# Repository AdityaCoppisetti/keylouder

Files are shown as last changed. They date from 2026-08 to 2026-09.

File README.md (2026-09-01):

hey im dhruv coppisetti and i love mechanical keyboards!
mainly 60 percents to be honest. 

with hackclub's macondo program where they fund you for the project that you make,
i decided that i should give this project a try and for the longest time i left it
abandoned because i couldn't figure out the keyboard layout, but then i watched a ton of
youtube tutorials and i got the hang of it. 

how is my keyboard different than other 60 percent keyboards?

well for starters its made completely by me including the pcb and the case and everything down to the tiniest bit

and then i did this really unique thing all because i had a tiny bit of space beneath the main controller of the keyboard (raspberry pi pico)
so i thought i should add a led matrix.

i was loooking at a tutorial where they had made their own led matrix module and it got me thinking what if i made my own
hotswappable modules

and so i did just that 

i made the keyboards pcb firstly and here is how that looks like 



but the wiring and the annotation was all wrong so i made it again plus i had totally forgotton to add stabilizers

so i made the schematic again and made a new pcb 



i landed with this pcb 



and the extra space beneath the pi pico gave me the idea and the space to add swappable modules 



and so i made a led matrix pcb and here is how that looks like 



the routing for this pcb took me A WHILLLEEE but i had  tons of fun doing it 
its really fun to take such tasks 

and the led matrix went onto the board so perfectly 

https://github.com/user-attachments/assets/e525fbdb-a991-4f65-9065-cdec64515798

and then i made 2 more modules 

the rotary encoder pcb which just changes the wiring 





i will be using that to adjust volume

and the most exciting part of the project is that i made a virtual pet inside the keyboard!

i made a tamagotchi module.

what a tamgotchi?

Tamagotchi is a brand of handheld digital pets created by Japanese toymaker Bandai, originally released in 1996.  The name is a portmanteau of the Japanese word tamago (egg) and watch, reflecting the device's egg-shaped design.

its a tiny digital pet 

i didnt have enough remaining pins on the pi pico so i made a esp32 devboard and then made it into a tiny module 





and then i wanted a skeleton case for the keyboard so i made this case on onshape 







although i might redesign the led matrix pcb again


im super duper excited to build this project when i get the funding for it. you can find all the resources i used in the journal.md in this repo

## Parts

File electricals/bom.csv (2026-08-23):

Module | Component | Quantity | Price (INR) | Link | Price (USD)
Keyboard | Raspberry Pi Pico | 1 | 1060 | https://amzn.in/d/02R50tLO | $11.08
Keyboard | 1N4148 DO-35 switching diode | 61 | 294 | https://robu.in/product/1n4148-onsemi-100v-1v10ma-4ns-200ma-do-35-switching-diodes-rohs/ | $3.07
Keyboard | Womier Retro Ruby Pink Cherry Doubleshot PBT Keycaps | 1 | 1899 | https://curiositycaps.in/products/womier-retro-ruby-pink-cherry-doubleshot-pbt-keycaps | $19.84
Keyboard | Blue mechanical switches | 90 | 2187 | https://amzn.in/d/03xjlYV7 | $22.85
Keyboard | Keyboard stabilizers | 1 | 1716 | https://amzn.in/d/0fbE7VLn | $17.93
Keyboard | 2.00mm pitch female Berg strip | 1 | 25 | https://robu.in/product/2mm-pitch-female-berg-strip-40x1-2pcs/ | $0.26
Keyboard | Keyboard PCB | 1 | 900 | robu.in | $9.40
Rotary Encoder | Rotary encoder module | 1 | 92 | https://robu.in/product/m274-360-degree-rotary-encoder-module-brick-sensor/ | $0.96
Rotary Encoder | Perfboard | 1 | 75 | https://amzn.in/d/09jRTxoF | $0.78
Rotary Encoder | 360-degree rotary encoder module | 1 | 92 | https://robu.in/product/m274-360-degree-rotary-encoder-module-brick-sensor/ | $0.96
LED Matrix | 100nF / 0.1uF 0603 SMD ceramic capacitor | 1 | 4.4 | https://robu.in/product/0603b104k101nt-fh-100v-100nf-x7r%c2%b110-0603-multilayer-ceramic-capacitors-mlcc-smd-smt-rohs/ | $0.05
LED Matrix | 10uF 0603 SMD ceramic capacitor | 1 | 39 | https://robu.in/product/zrb18ar61e106me01l-murata-smd-multilayer-ceramic-capacitor-10-%c2%b5f-25-v-0603-1608-metric-%c2%b1-20-x5r-zrb/ | $0.41
LED Matrix | 0603 SMD red LED | 64 | 133 | https://robu.in/product/19-217-r6c-al1m2vy-3t-everlight-red-528nm-led-indication-discrete-3-3v-0603-1608-metric/ | $1.39
LED Matrix | 10k 0603 SMD resistor | 1 | 4.8 | https://robu.in/product/yageo-10k-ohm-1-4w-0603-surface-mount-chip-resistor-pack-of-50/ | $0.05
LED Matrix | MAX7219 SMD IC | 1 | 128 | https://robu.in/product/max7219-ic-smd-package-8-digit-led-display-driver-ic/ | $1.34
LED Matrix | PCB | 1 | 900 | https://robu.in/ | $9.40
Tamagotchi | GC9A01 1.28-inch 240x240 round display | 1 | 519 | https://robu.in/product/goldenmorning-gc9a01-7p-240x240-spi-1-28-inch-round-display-module/ | $5.42
Tamagotchi | 6x6mm through-hole tactile switch | 1 | 7 | https://robu.in/product/tsd001a06026a-bzcn-6mm-6mm-50ma-round-button-direct-insert-6mm-12v-plugin-tactile-switches-rohs/ | $0.07
Tamagotchi | PCB | 1 | 900 | https://robu.in/ | $9.40
 |  |  |  | total amount is 115 dollars

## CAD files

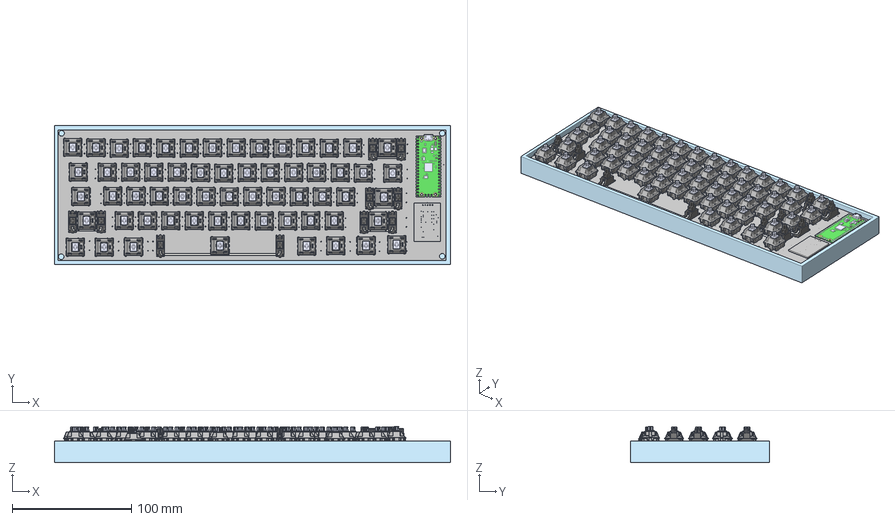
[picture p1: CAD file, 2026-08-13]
CAD/keyboard assembly.step
331.6 x 116.6 x 30.5 mm
Stabilizer_Cherry_MX_2.00u x 5
???___???__??___���___Ĭ��_ _��_ x 122
MX ?? ??????_????____MX �� ���娢��_ ���顧__ x 61
MX ?? ??????_??___??1__MX �� ������_ ��___��1 x 61
Stabilizer_Cherry_MX_2.00u_1 x 5
MX?? ???? ??? ???2__???_??2____??___MX�� ���� �ײ� �̡�2__Ĭ��_��2 ____��_ x 61
Stabilizer_Cherry_MX_2.00u_3 x 5
Stabilizer_Cherry_MX_2.00u_2 x 5
Stabilizer_Cherry_MX_6.25u x 5
led matrix_PCB
keeb_PCB
PICO

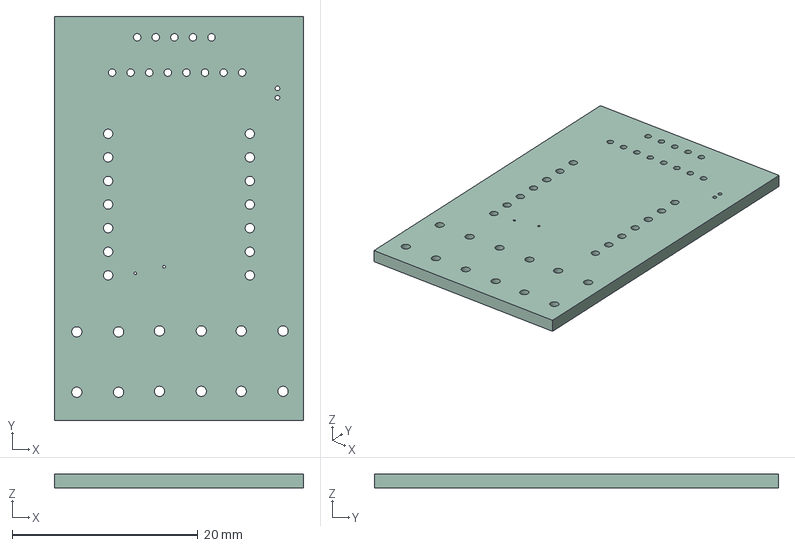
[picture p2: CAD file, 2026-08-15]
CAD/better tamagotchi module.step
26.8 x 43.5 x 1.51 mm

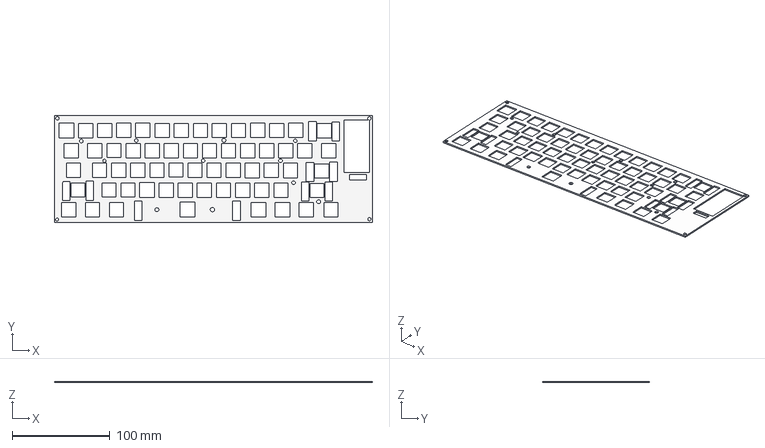
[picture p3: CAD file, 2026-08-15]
CAD/top plate.step
324.9 x 109.2 x 1.50 mm

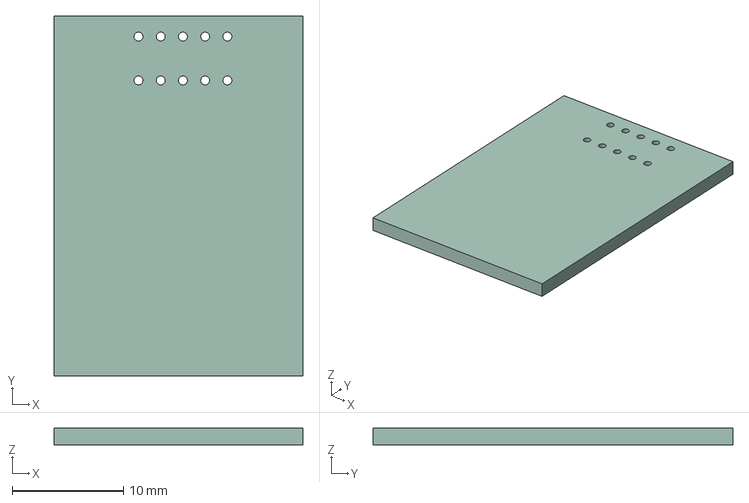
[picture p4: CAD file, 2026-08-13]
CAD/rotary encoder module.step
22.4 x 32.4 x 1.51 mm

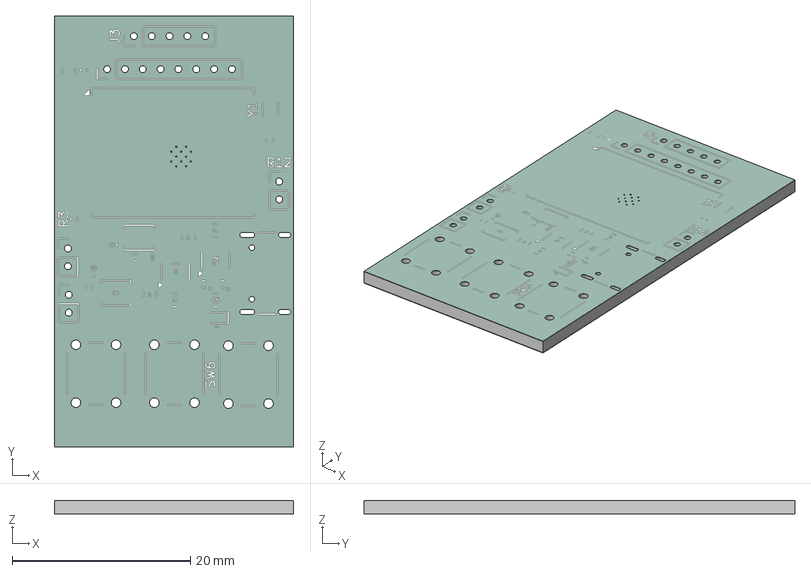
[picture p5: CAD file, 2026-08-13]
CAD/tamagotchi module.step
26.8 x 48.3 x 1.64 mm
tamagotchi module_silkscreen
tamagotchi module_soldermask x 2
tamagotchi module_PCB

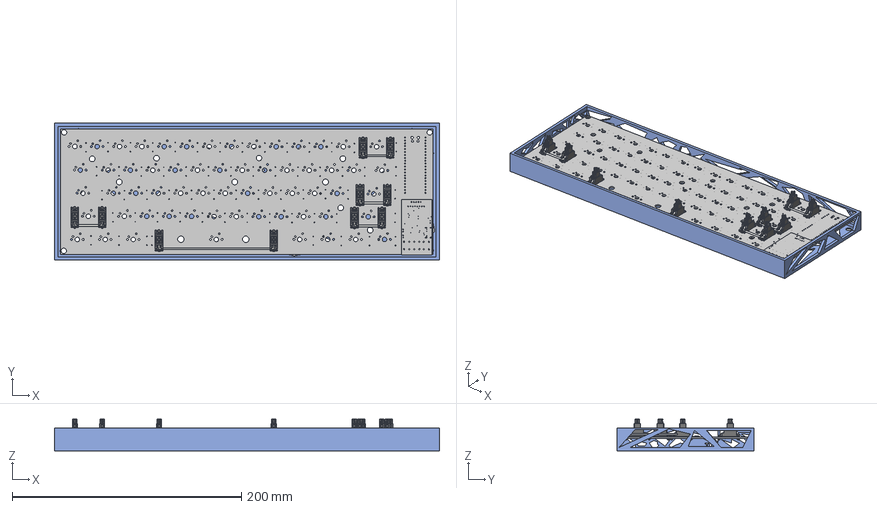
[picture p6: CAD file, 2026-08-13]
CAD/keylouder skeleton case version 1.step
335.8 x 119.3 x 27.8 mm
Stabilizer_Cherry_MX_2.00u_3 x 5
Stabilizer_Cherry_MX_2.00u x 5
Stabilizer_Cherry_MX_2.00u_1 x 5
tamagotchi module_PCB
Stabilizer_Cherry_MX_2.00u_2 x 5
Stabilizer_Cherry_MX_6.25u x 5
keeb_PCB

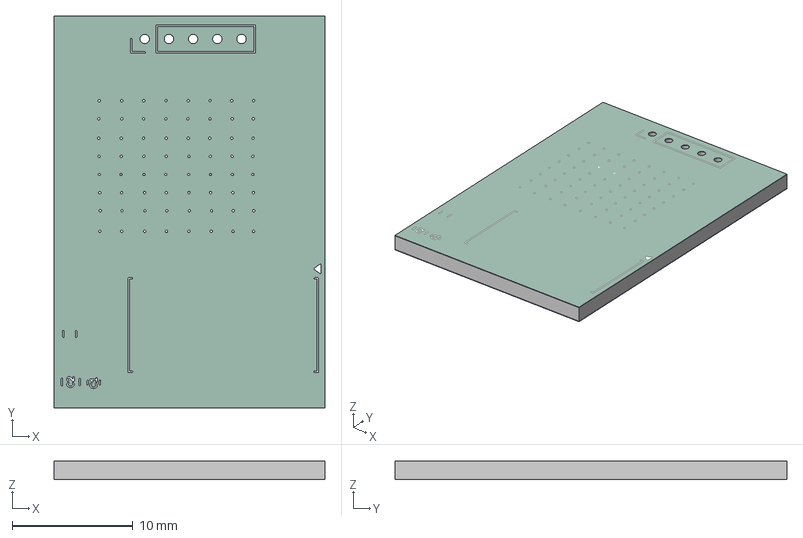
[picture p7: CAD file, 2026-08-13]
CAD/led matrix.step
22.4 x 32.4 x 1.64 mm
led matrix_silkscreen
led matrix_soldermask x 2
led matrix_PCB

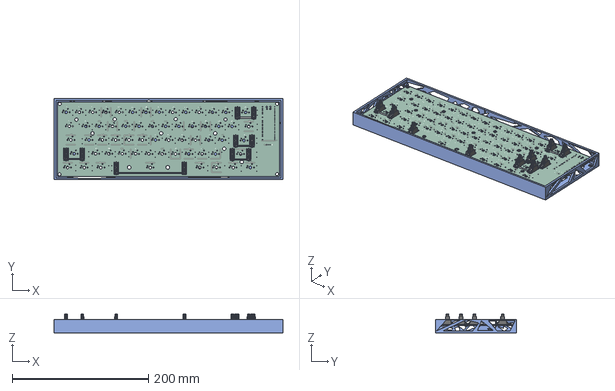
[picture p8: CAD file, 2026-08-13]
CAD/keylouder skeleton case final.step
335.8 x 119.3 x 27.8 mm

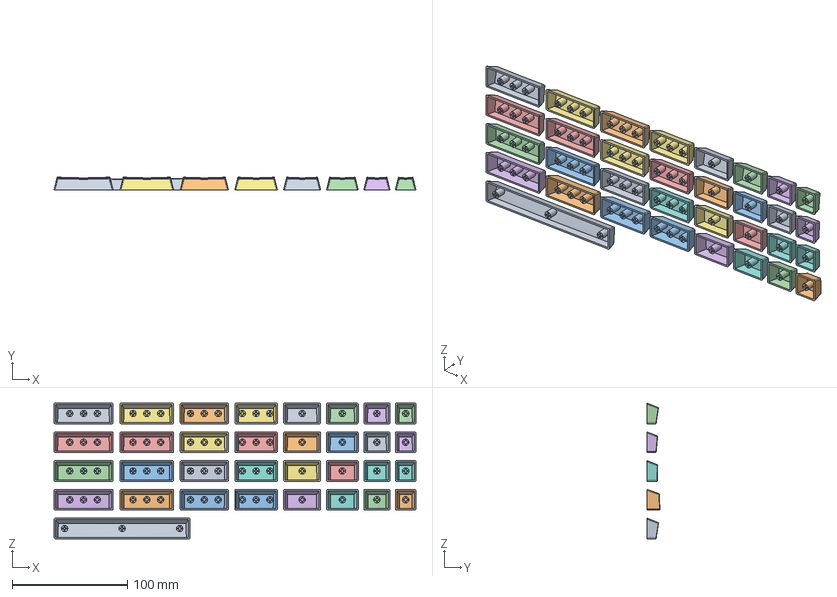
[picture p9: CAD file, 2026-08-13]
CAD/Cherry MX keycaps.step
314.7 x 11.2 x 118.0 mm

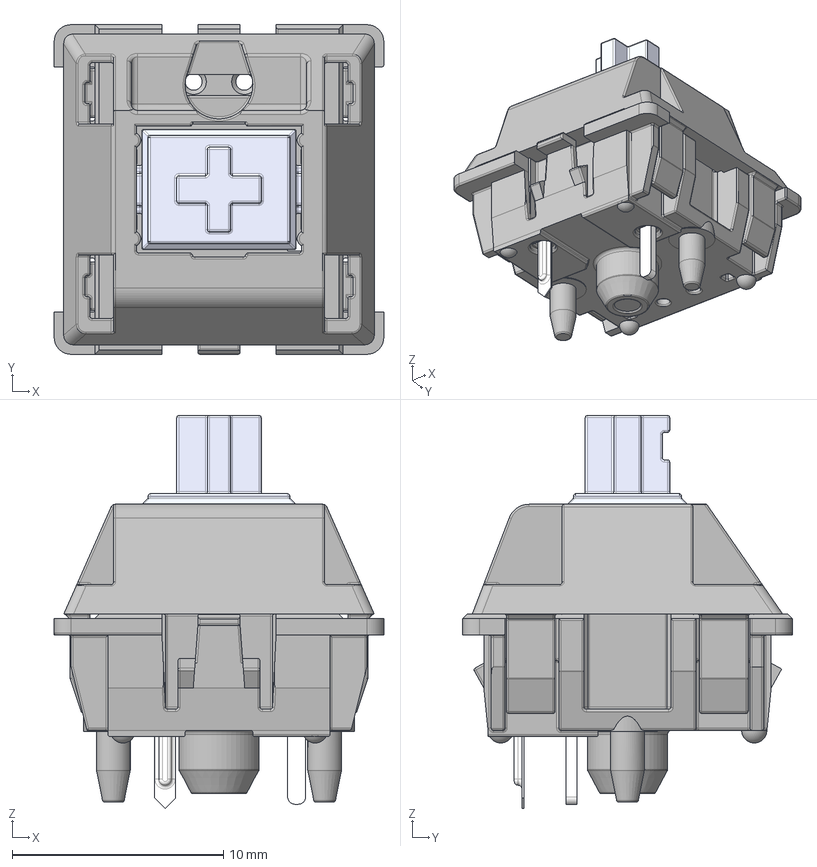
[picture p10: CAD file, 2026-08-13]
CAD/Cherry MX Keyswitch.step
15.6 x 15.6 x 18.6 mm

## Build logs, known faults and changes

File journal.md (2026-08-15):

i started this project back in june? 
i cant really rememeber but then i abandoned this project because i couldnt understand the keyboard layout and the pcb mapping. 
well some youtube tutorials later i figured how to make the layout. 

i went to this website to figure out the keyboard layout what is basically does is it shows you the keyboard layout and the size of the keys. 

https://editor.keyboard-tools.xyz/

you see something like this when you open the website , you can use whichever website you find comfortable, for me its this website. 



there are pre-existing presets , you can even build you custom presets,
then you can choose whichever keyboard layout you want.



i decided to make a 60% keyboard since i already have a 60% keyboard and i love its layout

it looks like this- 



and then you open kicad and then open schematic editor and take a switch and diode. 
why? 
because there are 61 switches and we are using the raspberry pico which clearly doesnt have the pins required to wire each switch seperately. 

# THE SCHEMATIC

so here is what we are going to do , we are going to make a matrix of switches in this manner- 



and then we will wire them up in rows and columns like this- 



3 rows and 3 columns, this is basic maths combination. 

okay ill quickly explain the wiring diagram. 

and the diodes are there so no swtiches falsly seem to be pressed , i.e ghost clicking

so basically each switch is now unique since it has a unique value . 
for example switch one is wired so that when pressed it'll be - row1 and column 1. and for switch 2 it'll be row2 and column1 

okay so using this idea we make the full schematic for the needed 61 keys ( because its 60%) 

okay so this schematic wiring is a bit wrong, i need to fix it but it explains the logic. 



see the rows and columns 

we will call this schematic version 1 



just for understanding the logic 

i even made the entire pcb but then i realised i wired everything wrong , here is that pcb i designed- 

Screenshot From 2026-08-11 15-16-31

okay i copied over the components and lets redesign the schematic . 



my goal is to make it the same as the layout 
because at first when i saw 61 keys i thought i could wire them in a 5x12 manner but turns out i need to do it how the layout is

in the top most layer there are 14 switches so we will wire 14 switches in the first column

in this way 



now see not each switchis of the same size , so how would we know what size of swtich we would need to use? 
well in the keyboard layout editor you click the switch and down below it shows the width , which is the size of the switch you need to use

this is for the backspace key 



and then you go into your footprint library and pick the correct size . im using cherry mx switches so my footprints may vary 

we want to pick the pcb one footprint as it has space for supports 
which we would need for the space bar and other big keys 



and we will repeat this method for each key 

in the second column we again have 14 keys but this time the switch sizes are different, 2 keys exactly 



and for our 3rd row we have 13 switches with the tab and enter key differenly sized



and in our 4th row we only have 12 keys 



my bad it turns out i miscounted the switches in my schematic in the top layer , it is indeed 14 but i put only 13 switches 

here is how it should look like 



in our 5th and last row we have only 8 switches so here is how the schematic looks like- 



here is the proper schematic with the rows and columns respectively 



okay so because you copy the rows and paste them to save time , you would have to annotate which renames the switches so dont freak out like me 



here are the footprints ive assigned everything





# THE PCB 

now lets load everything onto pcb editor and start designing our pcb 



oh and i decided to not use the rotary encoder , ill use it for a different project

and here is how i wired the pi pico 



okay so here is what im doing 
im taking each diode and putting it on the other side of the pcb 



and then im removing the refrences and values because all diodes are the same in my pcb

oh and btw the entire last colum has different sized switches



oh and apparently it took me this long to realise i didnt put the size for the space bar and didnt mention it in the schematic 



here it is now 



okay so at first i didnt account for stabilizers which you would need so that the keycaps stay flat on the keyboard. 
so i went to add stabilizers in my schematic but i couldnt find the symbol so i just took a capacitor and gave it that footprint. 
also the footprint for that i got from a different package which apparently has 3d models of everything so im going to switch the footprint of each key to one from that library. 

the reason i used capacitors is because i already mapped out the keys in the pcb and if i would have used switches instead of capacitors it wouldve had me annotate the pcb again which would mess everything up and i would have to start all over. 

secondly when choosing stabilizers you ignore whats after the decimal point in the size 



if the size is 2.25 , you pick 2, etc. 

okay so i completed the pcb routing completely 



now lets make the case 

here is how the pcb looks like in 3d view
and before we do that we have to define the pcb parameters using the edgecuts layer and drawing a rectangle. 



also then we are going to define a positive and ground plane 

and i went ahead and added VBUS and GND power symbols to the schematic 



after adding the VBUS fill zone here is how it looks like 



and then then GND one 



end result- 



look how much better the pcb looks 



and here is a lil 360 as always 

https://github.com/user-attachments/assets/9dbf6d89-2aa4-4465-9659-0ed4b1decdad

before we get started on the case i dont like the empty space below the pi pico so im thinking of adding a led matrix to it and have fun animations on it 

okay so i was reading this tutorial https://www.hackster.io/diyguyChris/diy-customized-8x8-led-matrix-tutorial-max7219-meets-arduin-06a3a7



and the person had built a tiny module for their arduino and it got me thinking what if i built my own module instead of letting the components be on the keyboard pcb.

now that open alot of doors because then i would be able to hotswappable modules like one with a led matrix and then one with a tiny oled display and one with a rotary encoder.
this is exciting!!

# THE LED MATRIX MODULE 

Using the schematic provided in the tutorial ill reacreate that schematic in kicad , lets make a new project file within our project and start building the schematic 

Screenshot From 2026-08-12 16-22-33

okay i wired the ic , 



now we need to make the led matrix and wire that to it 



made it now we need to wire it to the ic 

Okay i did it and here is how it looks like-



we now need to make the pinout 



okay i made a mistake the net labels werent the same because in the matrix the r is lowercase and in the ic wiring the net label was upercase 

# THE FOOTPRINTS 
For the leds this is the footprint im using- 



LED_SMD:LED_0201_0603Metric

for the ic im using this 



for the resistor 



and then the resisitor



# THE LED MATRIX PCB

but before we do that i need to see how much space we have below the pi pico in the keyboard pcb.

looks like we have plenty space



i finally got done routing everything oh my god its so time taking 



okay now lets design the case. 

## THE CASE

ookay so i opened kicad pcb editor and exported my file in . step 

Screenshot From 2026-08-12 14-28-17



now lets open onshape and import our pcb boards. 



combine it into the same part studio.

i do this because its so much easier to make the case then and then i make sure that nothing is mapped out wrong plus at the same time i create project mockups to use as the preview picture 

the pcb looks so amazing in onshape 



oh my god i totally forgot to add connecting pins for the led matrix bahahahah

okay so i added connection in the main keyboard schematic and let now also put it on the pcb 



before we do that lets clean up our schematic 

i personally like to keep everything neat so this part is upto you 



okay so i updated the main pcb here is how it looks like now



oh and i totally forgot i need to add holes to put screw thru so that i can mount it onto the case 

now our pcb has holes so i can put screws thru them and we will be using 4mm heat inserts in the case keep in mind. you can choose any heat inserts you want 



here is a lil 360 

https://github.com/user-attachments/assets/b619c04f-7e00-4aa9-93fa-9f7086f12ad5

now lets import this again into onshape and lets stard designing the case 

okay so im making this structure in the case which is totally optional but im making this so that the pcb is sturdy and doesnt bend from the weight of my hand 





oh and the holes in the corner are so i can put heat inserts and then screw down the keyboard 

okay so i made the case and i added a little hole for the c type port. im going to use a male to female c type wire and then route it beneath the pcb and into the hole 



here is how the pcb looks like inside the case 



the little led matrix sits so flush and perfectly on the board its crazy 

https://github.com/user-attachments/assets/e525fbdb-a991-4f65-9065-cdec64515798

okay so i found this key and keycap cad file and im downloading it to use for my mockup 





now im going to add everything together in assembly and design mockups 



my laptop is struggling really hard to load all of this bahahahha



my laptop is getting so hot 







i fear my laptop may fucking blast 



okay so i genuinly think something will blow up because of how laggy and hot my laptop is getting 



i want to make more modules , simple ones now , like a oled display module and then a rotary encoder module and 
 i want to add this sliding module aswell

now lets make the rotary encode module! 

 

 but i might make it for a different keyboard or project 

# ROTARY ENCODER MODULE!!!!!!!!!!!!!!!!

okay so ill be using this rotary encoder



okay so you can do this with a perfboard aswell. 

ill be desoldering the pins on the rotary encoder and then soldering the rotary encoder onto my module pcb because the pins we have set for gnd and vcc is different that the ones needed for the rotary encoder

OKAY SO BAHAHAHAHAHHAH THIS IS HOW BIG THE SCHEMATIC IS , ITS THE BIGGEST SCHEMATIC IVE EVER MADE



okay so what its basically doing is that it takes the pin on the main keyboard pcb and then makes it suitable for the rotary encoder 



and then these are the footprints 



this is how simple the module really is 



the most difficult pcb today oh my my 



there is literally no point in making fill zones but i think it gives the board a nice look 





and obviously ill import it into onshape and make a mockup 

apparently i cant do that because as soon as i open the asembly now it just freezes my laptop and im worried that my hackatime lapse footage will corrupt :(

# August 13th 10.30 am

yesterday night after i got done working i was thinking about what sort of modules i should make and i asked my friend and he recommended me to make a tamogotchi digital pet which would be so cool 

so let me figure out how to make that after i make just the plain oled display module

now i know i shouldnt let the pi pico do all of that so i will use my tiny xiao microcontroller 
that i have or im going to use the esp32 module the one that doesnt have bluetooth or wifi.

all of this seems really really cool and exciting! 

# the display 

okay so after browsing robu.in
i found this really cool round display module 



it is the GC9A01 7-pin, 240×240, 1.28-inch round TFT module, SKU R123209

it seems really simple to let me see if instead putting this display module ontop of my swappable module i can just make this into the same pcb 

and here is the given datasheet measurements of the display 



# the micrcontroller 

ill be using the ESP32-C3-WROOM-02U



its the same as the other esp32 module that i use besides the fact that it doesnt have inbuilt wifi and bluetooth antenna 

ive built multiple esp32 modules before so this shouldnt be a problem 

lets open kicad and get started 

okay so because there isnt a proper datasheet on how the schematic of the display is , ill just be using the display module itself rather than having a tft screen soldered down on my pcb 

# the buttons 



i will be using these tactile switches cause i really really like them 

## the schematic for tamagotchi module 



i have put the main parts now lets design the tiny esp 32 board

wired just the main module 



wired the power and data input 



okay here is everything 



now lets add display out and buttons 

here is the complete schematic with the buttons and display input

this is the footprint of the pcb 



now lets get started on the pcb 



 now lets make the pcb 

 ## the tamagotchi module pcb

  the 12mm switches were too big so i switched it to 6mm

  i forgot to add the input pins from the keyboard pcb 



the 3rd 4th and 5th pin do absolutely nothing 

i wired it so that the buttons are only using one pin because i didnt have any pins remaining for the display 



beacuse



each button will now have a unique value and thus we can use them with the same gpio pin 

okay so the pcb wiring is done i got so overstimulated i had to calm my mind down 



here is how the pcb looks like in 3d view 



and 



and obviously here is a little 360

https://github.com/user-attachments/assets/ace1704f-5848-4185-81a5-730ddb79b4bb

now lets see if i can try to make a mockup 
and also i want to build just one more module thats just a screen

also i want to rebuild the case and make it really really cool

i want to give the case a skeleton look 

i have something like this in mind 



 i dont want to mess my previous case up so im creating a different onshape document entirely and exporting the pcb again

 i made holes in the pcb so i could screw it in and mount it , i however think that the holes ive made are too big so i might have to design a specific washer 

 Screenshot From 2026-08-13 17-39-40

i have made the outline of the case now lets remove parts using extrude feature and make it look cool asf 



this is what im thinking about also this looks so bad but ykw its something that represents me 



okay so i did another side and i pray to go this looks better in life 



aaaandddd another side done , wont be doing it on one side and then ill do the bottom layer 



just made the bottom layer sketch



i mean i guess it'll work 



made the bottom layer sketch in the skeleton case manner lets see if its any good 



now lets see if the tamagotchi module will fit 

the tamagotchi module will definitely fit for sure 



this is such a cool project 



well its a first so im happy with it 



but let me still once try redesigning the bottom layer 

made a much much MUCH better sketch 



i made a couple of changes and now here is the final product 



made just one more tiny hole 



i also want to add images to my silkscreen but ill do it at the very last 

## august 15th 

today ill be doing a couple of things. 
i honestly thought i was almost done because i had made the case and everything. 
it turns out there was still alot i need to make- 

1) i want to add backlight to the keyboard however i dont want to do anything too fancy
2) i want to make the tamagotchi module better by using a xiao rp2040 and not using a esp32 however i will still be making that
3) i need to make the middle plate for the keyboard apparently
4) i want to add images on my silkscreen

but my question is how will there be backlight if im using a middle plate?

i mapped everything out and here is how the sketch of the mid plate looks like 



and im glad i did that because i realised that i didnt made the case mounting holes tall so the pcb would have been mounted really really low 
when i extrude that sketch i want it to be really really slim 

here is how it looks like when extruded



i went ahead and made the moutning holes in the case smaller 



and then i made the stand-offs and it lowk looks okayish i mean its not the best



in my previous case design i made a little cutout for the usb wire but i now realised i wouldnt need that since the pi pico is on pinheaders and thus it'll have some height yk and so i wouldnt have any problem with connecting it to a wire , however i dont think the pi pico comes in type c



# now lets make the tamagotchi module better 

im going to be using the xiao rp2040 because i already have that and you can use a perfboard for this aswell

this is the symbol and footprint





also i think im going to redesign the case oh lord 

i went ahead and designed the schematic



and then here are the footprints



## now lets make the pcb 

look at how little components we need in this and how simpler it is 

i copied and pasted the pcb measurements and the pin header positions

it seems like i did the wiring perfectly 

the pcb is super simple 

i made it so that the xiao rp2040 is on the other side of the board 



these board are so simple that ill be making them using a perf board , only the simple ones tho 

ive also added a bvuzzer and i totally forgot to update my pcb and add the pins for that and i hadnt connected the power input for the xiao 

and here is how it looks like after its updated and fully wired 



now lets export it into .step and make mockups 

okay so here is how that looks like 



oh yeah and i changed the middle plate colour to blue because grey was really weird

let redesign the case for the 3rd fucking time now

also before i do that , it seems like i made the mounting holes in the pcb way too big 
and also lets add images to silkscreen

here is the updated pcb with the correct mounting holes 



here it is in 3d viewer



and the back 



and obviously here is the lil 360 

https://github.com/user-attachments/assets/513a91aa-45da-4924-ba17-3ebb43d4cd46

here is the new case design sketch also i realised this is the fourth version of the case 



fingers crossed i hope this looks good 



okay moment of truth now i made the extruding layer 



honestly if we werent removing , this would look so cool if extruded that way 



apparently i had a lot of errors the way i had plotted the shaped to be removed and finally after so many trials 



okay it doesnt look that good but i have an idea , i have an old acrylic glass panel lying around and i think im going to put between the pcb and the case

now lets get started on the other sides

another side done 



and then another side done 



anddd



only one side remaining now 

also i decided not to add rbg because i never end up using it on my keyboard that i have and figured why go thru the hassle

done



 now lets make the standoffs

 make the sketch now lets extrude 

 

after the extrude
 

 now lets put the middle plate on 

 the middle plate looks so good!

 

looks so good 

**
**
 
apparently i forgot to add holes in the standoffs so there wasnt a hole to screw in but its good now

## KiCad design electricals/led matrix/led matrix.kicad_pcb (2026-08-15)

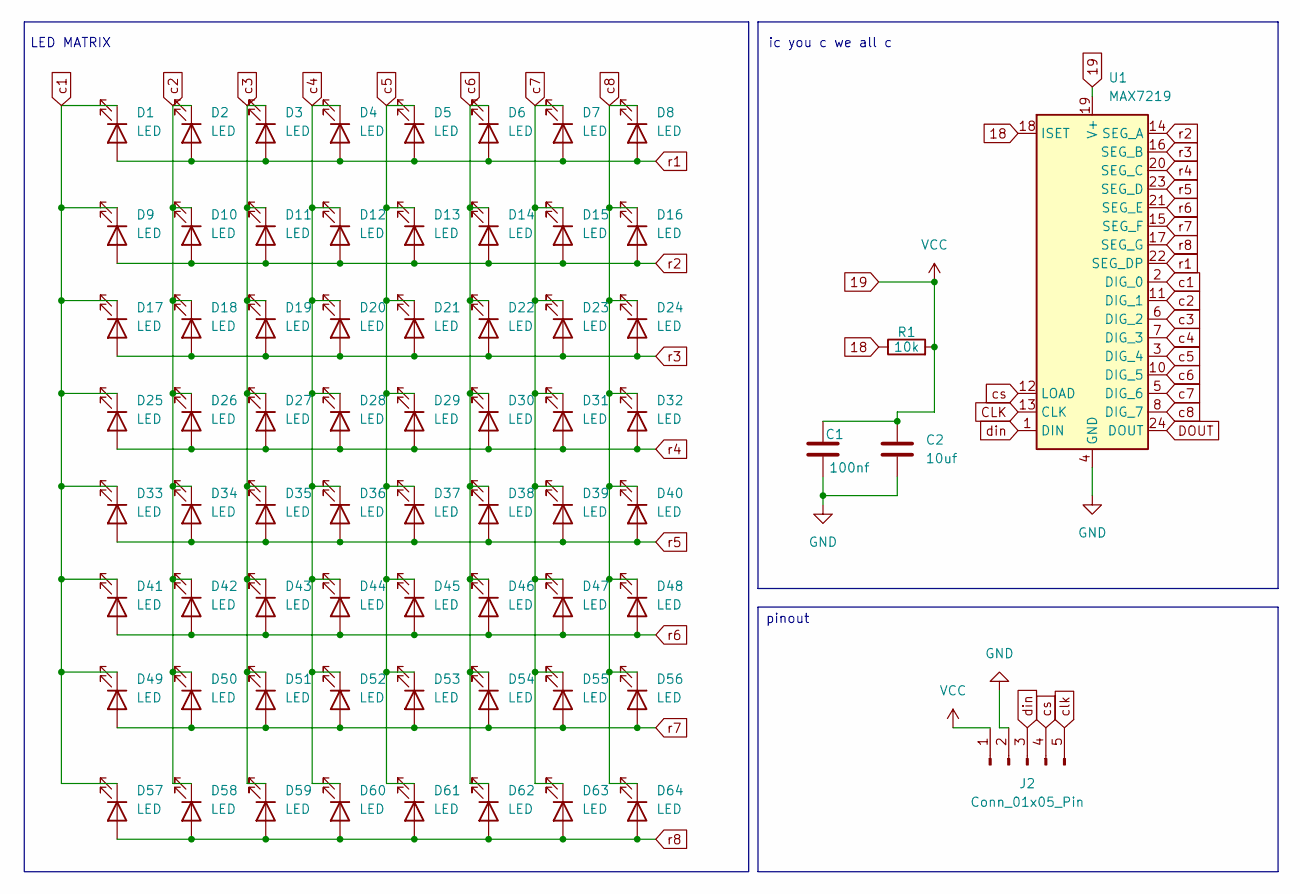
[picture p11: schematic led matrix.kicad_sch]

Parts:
C1: 100nf; C_0603_1608Metric
C2: 10uf; C_0805_2012Metric
D1, D2, D3, D4, D5, D6, D7, D8, D9, D10, D11, D12, D13, D14, D15, D16, D17, D18, D19, D20, D21, D22, D23, D24, D25, D26, D27, D28, D29, D30, D31, D32, D33, D34, D35, D36, D37, D38, D39, D40, D41, D42, D43, D44, D45, D46, D47, D48, D49, D50, D51, D52, D53, D54, D55, D56, D57, D58, D59, D60, D61, D62, D63, D64: LED; LED_0201_0603Metric
J2: Conn_01x05_Pin; PinHeader_1x05_P2.00mm_Vertical
R1: 10k; R_0603_1608Metric
U1: MAX7219; SOIC-24W_7.5x15.4mm_P1.27mm

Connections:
18: R1.1, U1.18 (ISET)
19: C1.1, C2.1, J2.1, R1.2, U1.19 (V+)
DOUT: U1.24 (DOUT)
GND: C1.2, C2.2, J2.2, U1.4 (GND), U1.9 (GND)
c1: D1.1 (K), D9.1 (K), D17.1 (K), D25.1 (K), D33.1 (K), D41.1 (K), D49.1 (K), D57.1 (K), U1.2 (DIG_0)
c2: D2.1 (K), D10.1 (K), D18.1 (K), D26.1 (K), D34.1 (K), D42.1 (K), D50.1 (K), D58.1 (K), U1.11 (DIG_1)
c3: D3.1 (K), D11.1 (K), D19.1 (K), D27.1 (K), D35.1 (K), D43.1 (K), D51.1 (K), D59.1 (K), U1.6 (DIG_2)
c4: D4.1 (K), D12.1 (K), D20.1 (K), D28.1 (K), D36.1 (K), D44.1 (K), D52.1 (K), D60.1 (K), U1.7 (DIG_3)
c5: D5.1 (K), D13.1 (K), D21.1 (K), D29.1 (K), D37.1 (K), D45.1 (K), D53.1 (K), D61.1 (K), U1.3 (DIG_4)
c6: D6.1 (K), D14.1 (K), D22.1 (K), D30.1 (K), D38.1 (K), D46.1 (K), D54.1 (K), D62.1 (K), U1.10 (DIG_5)
c7: D7.1 (K), D15.1 (K), D23.1 (K), D31.1 (K), D39.1 (K), D47.1 (K), D55.1 (K), D63.1 (K), U1.5 (DIG_6)
c8: D8.1 (K), D16.1 (K), D24.1 (K), D32.1 (K), D40.1 (K), D48.1 (K), D56.1 (K), D64.1 (K), U1.8 (DIG_7)
clk: J2.5, U1.13 (CLK)
cs: J2.4, U1.12 (LOAD)
din: J2.3, U1.1 (DIN)
r1: D1.2 (A), D2.2 (A), D3.2 (A), D4.2 (A), D5.2 (A), D6.2 (A), D7.2 (A), D8.2 (A), U1.22 (SEG_DP)
r2: D9.2 (A), D10.2 (A), D11.2 (A), D12.2 (A), D13.2 (A), D14.2 (A), D15.2 (A), D16.2 (A), U1.14 (SEG_A)
r3: D17.2 (A), D18.2 (A), D19.2 (A), D20.2 (A), D21.2 (A), D22.2 (A), D23.2 (A), D24.2 (A), U1.16 (SEG_B)
r4: D25.2 (A), D26.2 (A), D27.2 (A), D28.2 (A), D29.2 (A), D30.2 (A), D31.2 (A), D32.2 (A), U1.20 (SEG_C)
r5: D33.2 (A), D34.2 (A), D35.2 (A), D36.2 (A), D37.2 (A), D38.2 (A), D39.2 (A), D40.2 (A), U1.23 (SEG_D)
r6: D41.2 (A), D42.2 (A), D43.2 (A), D44.2 (A), D45.2 (A), D46.2 (A), D47.2 (A), D48.2 (A), U1.21 (SEG_E)
r7: D49.2 (A), D50.2 (A), D51.2 (A), D52.2 (A), D53.2 (A), D54.2 (A), D55.2 (A), D56.2 (A), U1.15 (SEG_F)
r8: D57.2 (A), D58.2 (A), D59.2 (A), D60.2 (A), D61.2 (A), D62.2 (A), D63.2 (A), D64.2 (A), U1.17 (SEG_G)

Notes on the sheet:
pinout
ic you c we all c
LED MATRIX

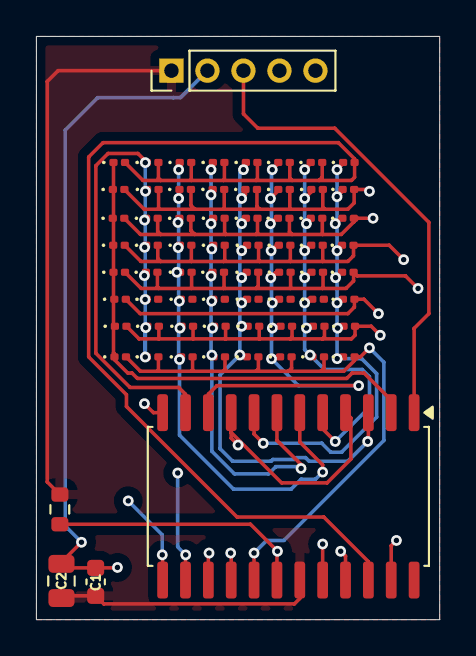
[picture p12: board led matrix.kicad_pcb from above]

Board: 4 copper layers, 22.4 x 32.4 mm, 69 parts (0 on the bottom side), 22 nets.

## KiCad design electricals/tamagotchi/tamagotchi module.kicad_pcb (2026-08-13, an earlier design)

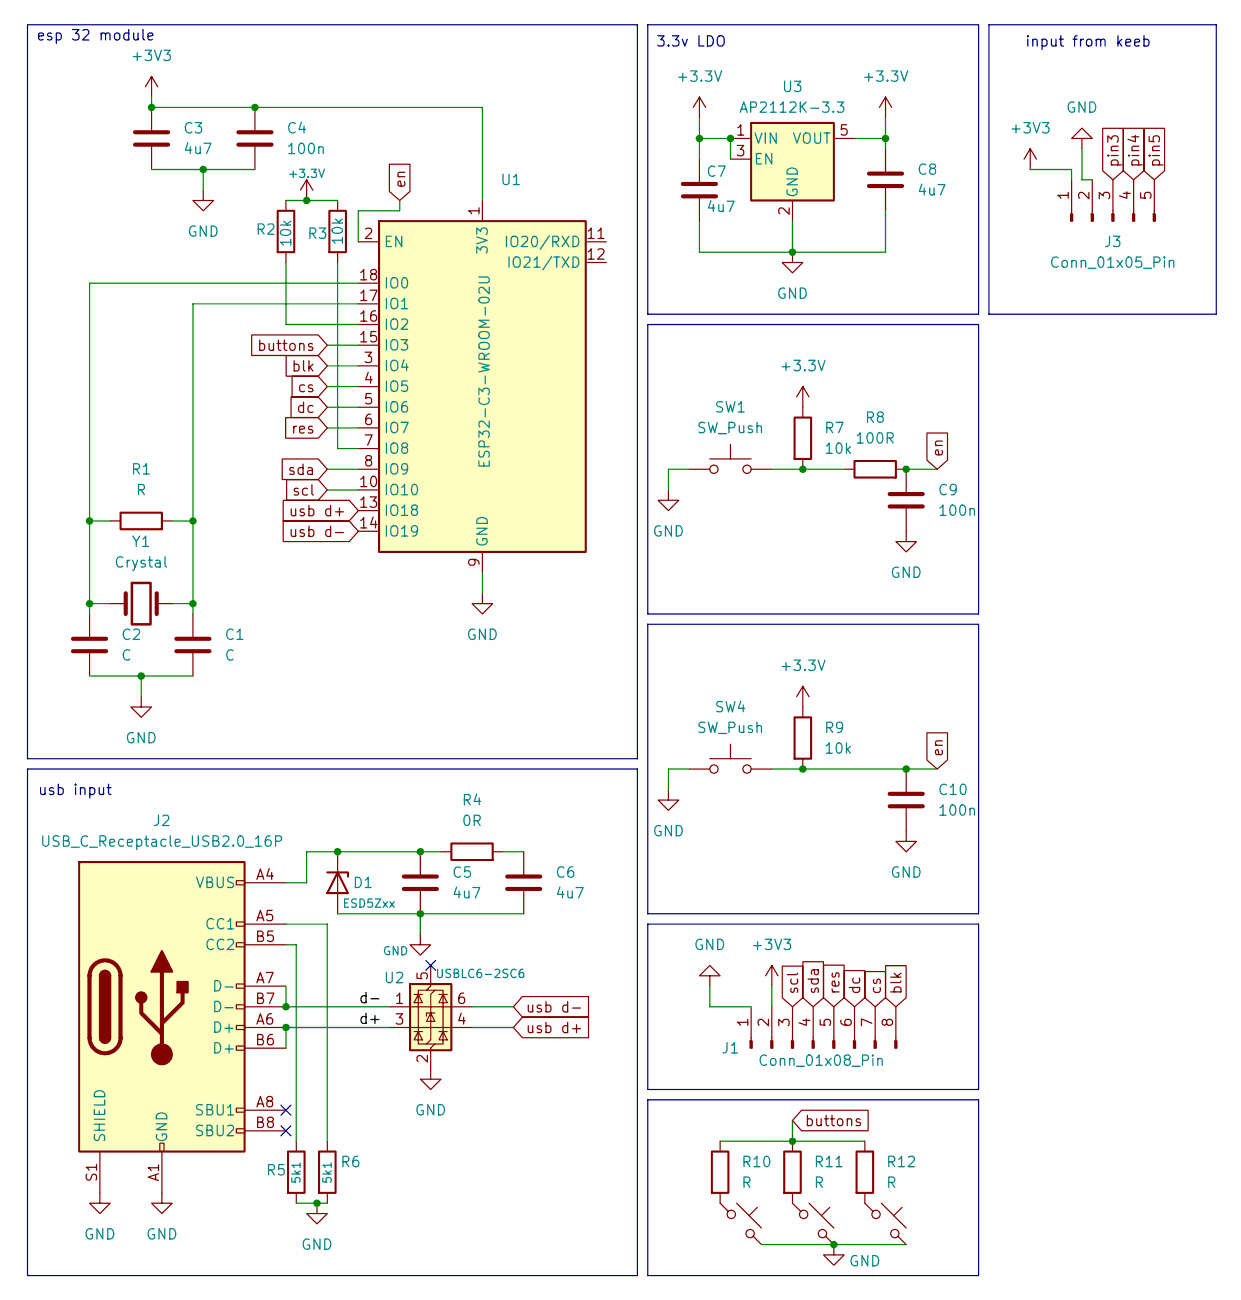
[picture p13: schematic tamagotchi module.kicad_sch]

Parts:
C1, C2: C; C_0201_0603Metric
C3, C5, C6, C7, C8: 4u7; C_0805_2012Metric
C4, C9, C10: 100n; C_0402_1005Metric
D1: ESD5Zxx; D_SOD-523
J1: Conn_01x08_Pin; PinHeader_1x08_P2.00mm_Vertical
J2: USB_C_Receptacle_USB2.0_16P; USB_C_Receptacle_G-Switch_GT-USB-7010ASV
J3: Conn_01x05_Pin; PinHeader_1x05_P2.00mm_Vertical
R1: R; R_0201_0603Metric
R2, R3, R7, R9: 10k; R_0402_1005Metric
R4: 0R; R_0805_2012Metric
R5, R6: 5k1; R_0402_1005Metric
R8: 100R; R_0402_1005Metric
R10, R11, R12: R; PinHeader_1x02_P2.00mm_Vertical
SW1, SW4: SW_Push; SW_SPST_B3U-1000P
SW2, SW3, SW6: SW_Push_45deg; SW_PUSH_6mm
U1: ESP32-C3-WROOM-02U
U2: USBLC6-2SC6; SOT-23-6
U3: AP2112K-3.3; SOT-23-5
Y1: Crystal; Crystal_SMD_3215-2Pin_3.2x1.5mm

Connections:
+3.3V: C7.1, C8.1, R2.1, R3.1, R7.1, R9.1, U3.1 (VIN), U3.3 (EN), U3.5 (VOUT)
+3V3: C3.1, C4.1, J1.2, J3.1, U1.1 (3V3)
/d+: J2.A6 (D+), J2.B6 (D+), U2.3 (I/O2)
/d-: J2.A7 (D-), J2.B7 (D-), U2.1 (I/O1)
GND: C1.2, C2.2, C3.2, C4.2, C5.2, C6.2, C7.2, C8.2, C9.2, C10.2, D1.2 (A), J1.1, J2.A1 (GND), J2.A12 (GND), J2.B1 (GND), J2.B12 (GND), J2.S1 (SHIELD), J3.2, R5.2, R6.2, SW1.1, SW2.2, SW3.2, SW4.1, SW6.2, U1.9 (GND), U1.19 (GND), U2.2 (GND), U3.2 (GND)
unnamed: C6.1, R4.2
unnamed: C5.1, D1.1 (K), J2.A4 (VBUS), J2.A9 (VBUS), J2.B4 (VBUS), J2.B9 (VBUS), R4.1
unnamed: J2.A5 (CC1), R6.1
unnamed: J2.B5 (CC2), R5.1
unnamed: R7.2, R8.1, SW1.2
unnamed: R10.2, SW3.1
unnamed: R11.2, SW2.1
unnamed: R12.2, SW6.1
unnamed: C2.1, R1.1, U1.18 (IO0), Y1.1
unnamed: C1.1, R1.2, U1.17 (IO1), Y1.2
unnamed: R2.2, U1.16 (IO2)
unnamed: R3.2, U1.7 (IO8)
blk: J1.8, U1.3 (IO4)
buttons: R10.1, R11.1, R12.1, U1.15 (IO3)
cs: J1.7, U1.4 (IO5)
dc: J1.6, U1.5 (IO6)
en: C9.1, C10.1, R8.2, R9.2, SW4.2, U1.2 (EN)
pin3: J3.3
pin4: J3.4
pin5: J3.5
res: J1.5, U1.6 (IO7)
scl: J1.3, U1.10 (IO10)
sda: J1.4, U1.8 (IO9)
usb d+: U1.13 (IO18), U2.4 (I/O2)
usb d-: U1.14 (IO19), U2.6 (I/O1)

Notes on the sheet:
3.3v LDO
usb input
esp 32 module
input from keeb

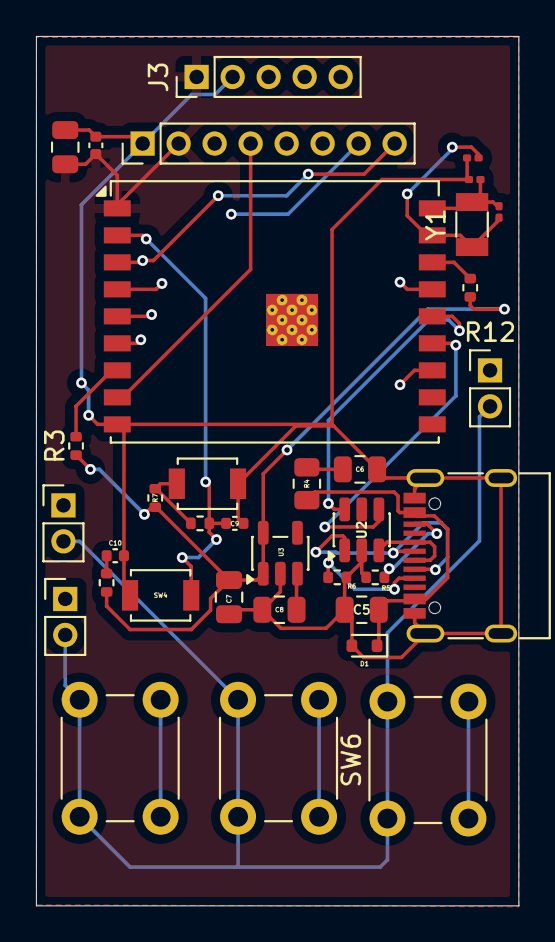
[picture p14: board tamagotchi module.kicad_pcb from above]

Board: 4 copper layers, 26.8 x 48.3 mm, 35 parts (0 on the bottom side), 27 nets.

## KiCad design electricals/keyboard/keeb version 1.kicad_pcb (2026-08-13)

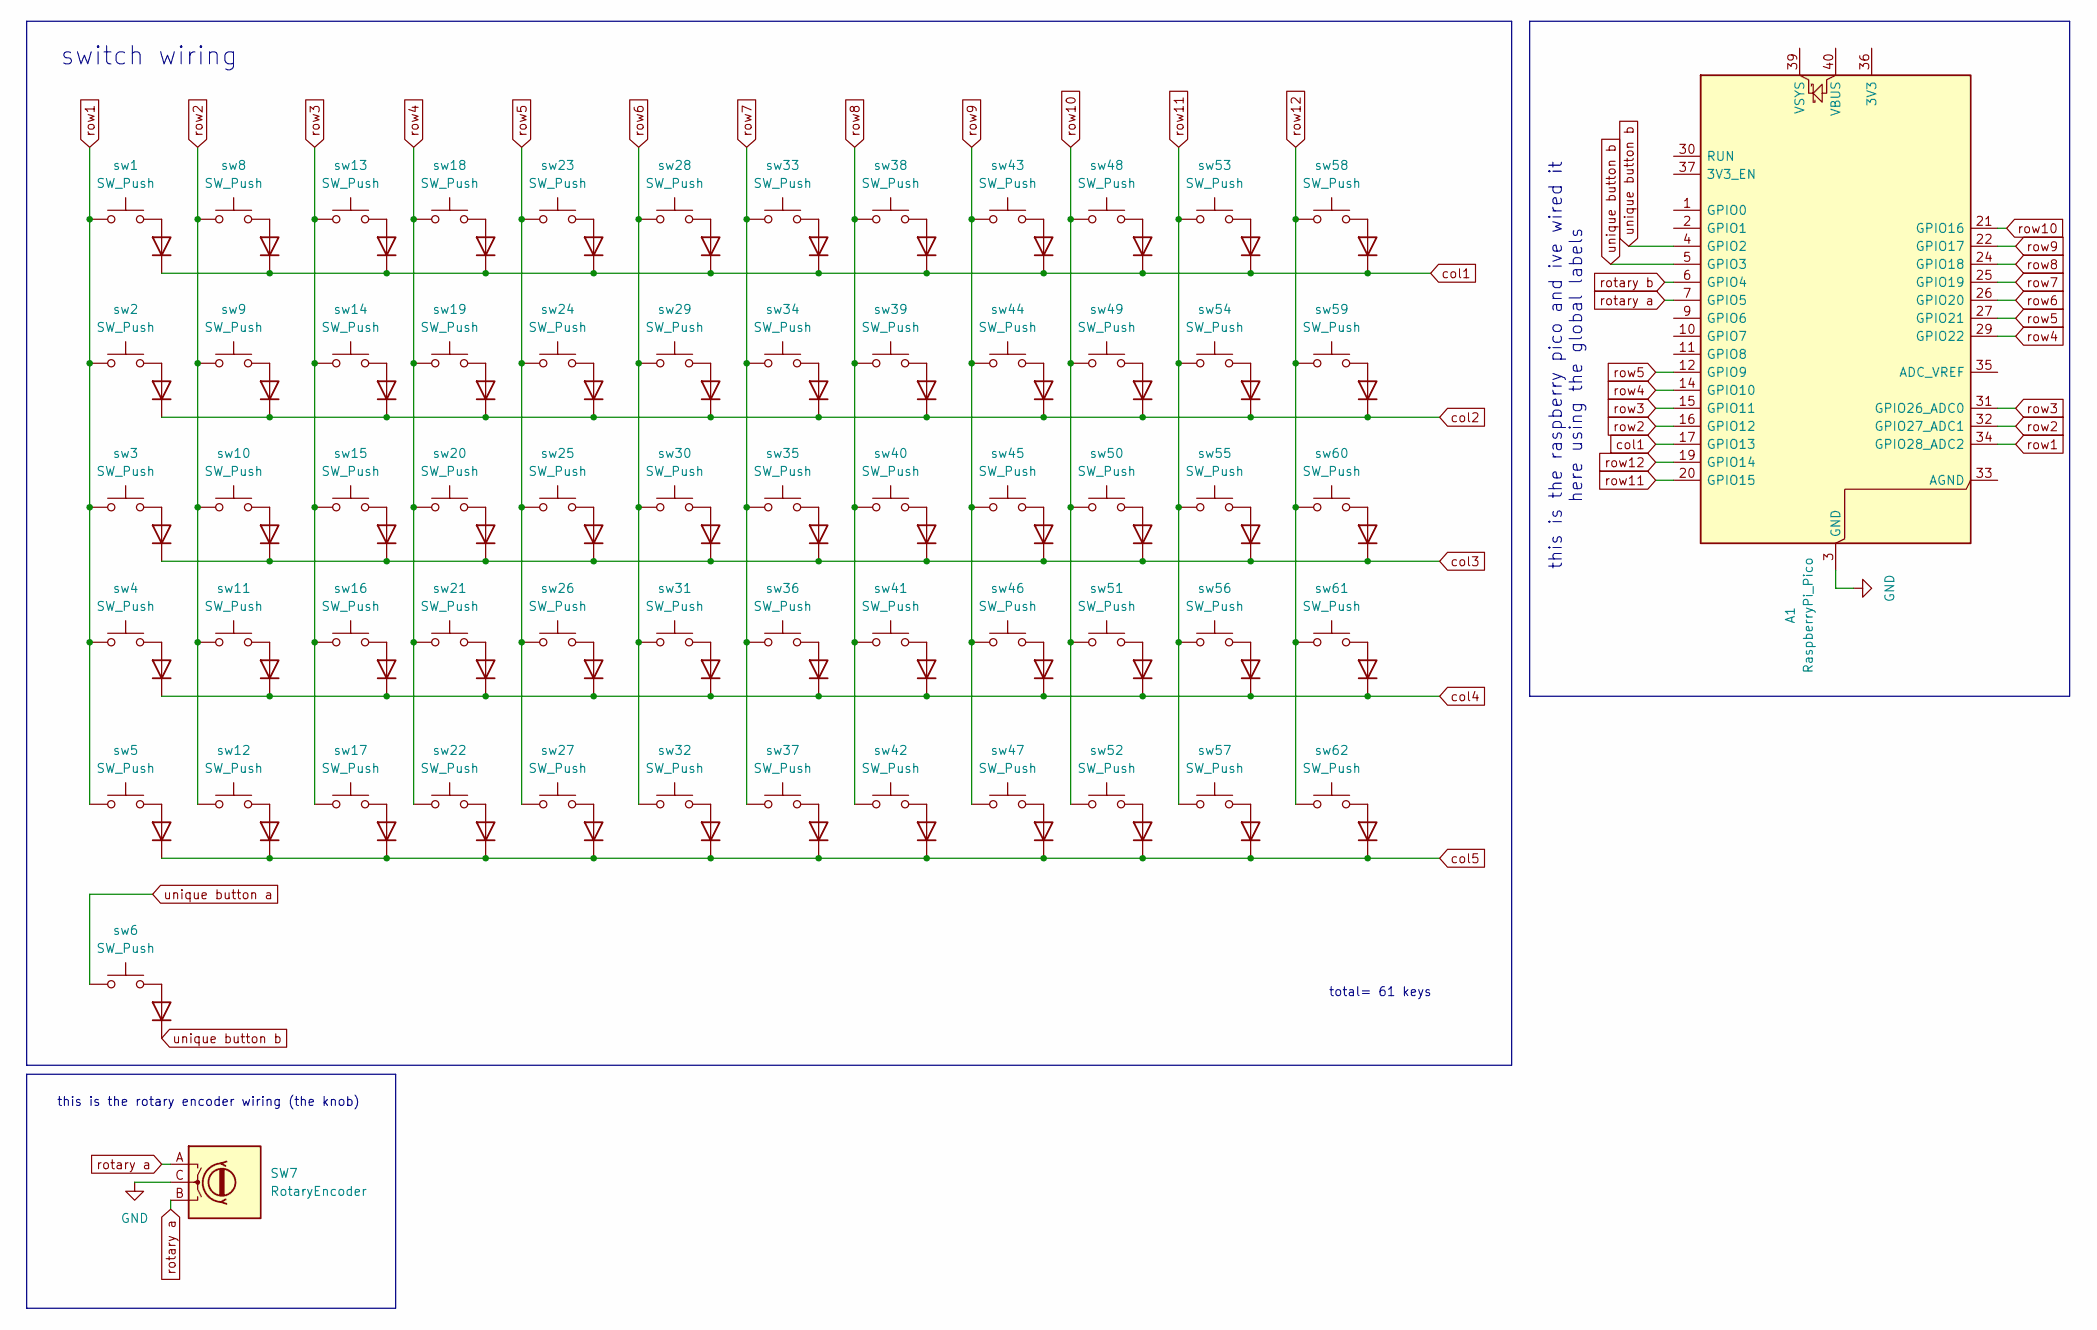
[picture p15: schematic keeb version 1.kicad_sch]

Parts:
A1: RaspberryPi_Pico; RaspberryPi_Pico_Common_Unspecified
D1, D2, D3, D4, D5, D6, D7, D8, D9, D10, D11, D12, D13, D14, D15, D16, D17, D18, D19, D20, D21, D22, D23, D24, D25, D26, D27, D28, D29, D30, D31, D32, D33, D34, D35, D36, D37, D38, D39, D40, D41, D42, D43, D44, D45, D46, D47, D48, D49, D50, D51, D52, D53, D54, D55, D56, D57, D58, D59, D60, D61: 1N4148; D_DO-35_SOD27_P7.62mm_Horizontal
SW7: RotaryEncoder; RotaryEncoder_Alps_EC11E-Switch_Vertical_H20mm
sw1, sw2, sw3, sw4, sw5, sw8, sw10, sw11, sw12, sw13, sw15, sw16, sw17, sw18, sw19, sw21, sw22, sw23, sw24, sw28, sw29, sw30, sw33, sw34, sw35, sw36, sw38, sw39, sw40, sw41, sw43, sw44, sw45, sw46, sw48, sw49, sw50, sw51, sw53, sw54, sw55, sw56, sw58, sw59, sw60, sw61: SW_Push; SW_Cherry_MX_1.00u_PCB
sw6, sw32, sw37, sw42, sw52, sw57, sw62: SW_Push; SW_Cherry_MX_1.25u_PCB
sw9: SW_Push; SW_Cherry_MX_2.00u_PCB
sw14, sw20: SW_Push; SW_Cherry_MX_1.50u_PCB
sw25: SW_Push; SW_Cherry_MX_1.75u_PCB
sw26, sw31: SW_Push; SW_Cherry_MX_2.25u_PCB
sw27: SW_Push; SW_Cherry_MX_2.75u_PCB
sw47: SW_Push; SW_Cherry_MX_6.25u_PCB

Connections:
GND: A1.3 (GND), A1.8 (GND), A1.13 (GND), A1.18 (GND), A1.23 (GND), A1.28 (GND), A1.38 (GND), SW7.C
unnamed: D1.2 (A), sw1.2
unnamed: D2.2 (A), sw2.2
unnamed: D3.2 (A), sw3.2
unnamed: D4.2 (A), sw4.2
unnamed: D5.2 (A), sw5.2
unnamed: D6.2 (A), sw6.2
unnamed: D7.2 (A), sw8.2
unnamed: D8.2 (A), sw9.2
unnamed: D9.2 (A), sw10.2
unnamed: D10.2 (A), sw11.2
unnamed: D11.2 (A), sw12.2
unnamed: D12.2 (A), sw13.2
unnamed: D13.2 (A), sw14.2
unnamed: D14.2 (A), sw15.2
unnamed: D15.2 (A), sw16.2
unnamed: D16.2 (A), sw17.2
unnamed: D17.2 (A), sw18.2
unnamed: D18.2 (A), sw19.2
unnamed: D19.2 (A), sw20.2
unnamed: D20.2 (A), sw21.2
unnamed: D21.2 (A), sw22.2
unnamed: D22.2 (A), sw23.2
unnamed: D23.2 (A), sw24.2
unnamed: D24.2 (A), sw25.2
unnamed: D25.2 (A), sw26.2
unnamed: D26.2 (A), sw27.2
unnamed: D27.2 (A), sw28.2
unnamed: D28.2 (A), sw29.2
unnamed: D29.2 (A), sw30.2
unnamed: D30.2 (A), sw31.2
unnamed: D31.2 (A), sw32.2
unnamed: D32.2 (A), sw33.2
unnamed: D33.2 (A), sw34.2
unnamed: D34.2 (A), sw35.2
unnamed: D35.2 (A), sw36.2
unnamed: D36.2 (A), sw37.2
unnamed: D37.2 (A), sw38.2
unnamed: D38.2 (A), sw39.2
unnamed: D39.2 (A), sw40.2
unnamed: D40.2 (A), sw41.2
unnamed: D41.2 (A), sw42.2
unnamed: D42.2 (A), sw43.2
unnamed: D43.2 (A), sw44.2
unnamed: D44.2 (A), sw45.2
unnamed: D45.2 (A), sw46.2
unnamed: D46.2 (A), sw47.2
unnamed: D47.2 (A), sw48.2
unnamed: D48.2 (A), sw49.2
unnamed: D49.2 (A), sw50.2
unnamed: D50.2 (A), sw51.2
unnamed: D51.2 (A), sw52.2
unnamed: D52.2 (A), sw53.2
unnamed: D53.2 (A), sw54.2
unnamed: D54.2 (A), sw55.2
unnamed: D55.2 (A), sw56.2
unnamed: D56.2 (A), sw57.2
unnamed: D57.2 (A), sw58.2
unnamed: D58.2 (A), sw59.2
unnamed: D59.2 (A), sw60.2
unnamed: D60.2 (A), sw61.2
unnamed: D61.2 (A), sw62.2
col1: A1.17 (GPIO13), D1.1 (K), D7.1 (K), D12.1 (K), D17.1 (K), D22.1 (K), D27.1 (K), D32.1 (K), D37.1 (K), D42.1 (K), D47.1 (K), D52.1 (K), D57.1 (K)
col2: D2.1 (K), D8.1 (K), D13.1 (K), D18.1 (K), D23.1 (K), D28.1 (K), D33.1 (K), D38.1 (K), D43.1 (K), D48.1 (K), D53.1 (K), D58.1 (K)
col3: D3.1 (K), D9.1 (K), D14.1 (K), D19.1 (K), D24.1 (K), D29.1 (K), D34.1 (K), D39.1 (K), D44.1 (K), D49.1 (K), D54.1 (K), D59.1 (K)
col4: D4.1 (K), D10.1 (K), D15.1 (K), D20.1 (K), D25.1 (K), D30.1 (K), D35.1 (K), D40.1 (K), D45.1 (K), D50.1 (K), D55.1 (K), D60.1 (K)
col5: D5.1 (K), D11.1 (K), D16.1 (K), D21.1 (K), D26.1 (K), D31.1 (K), D36.1 (K), D41.1 (K), D46.1 (K), D51.1 (K), D56.1 (K), D61.1 (K)
rotary a: A1.7 (GPIO5), SW7.A, SW7.B
rotary b: A1.6 (GPIO4)
row1: A1.34 (GPIO28_ADC2), sw1.1, sw2.1, sw3.1, sw4.1, sw5.1
row2: A1.16 (GPIO12), A1.32 (GPIO27_ADC1), sw8.1, sw9.1, sw10.1, sw11.1, sw12.1
row3: A1.15 (GPIO11), A1.31 (GPIO26_ADC0), sw13.1, sw14.1, sw15.1, sw16.1, sw17.1
row4: A1.14 (GPIO10), A1.29 (GPIO22), sw18.1, sw19.1, sw20.1, sw21.1, sw22.1
row5: A1.12 (GPIO9), A1.27 (GPIO21), sw23.1, sw24.1, sw25.1, sw26.1, sw27.1
row6: A1.26 (GPIO20), sw28.1, sw29.1, sw30.1, sw31.1, sw32.1
row7: A1.25 (GPIO19), sw33.1, sw34.1, sw35.1, sw36.1, sw37.1
row8: A1.24 (GPIO18), sw38.1, sw39.1, sw40.1, sw41.1, sw42.1
row9: A1.22 (GPIO17), sw43.1, sw44.1, sw45.1, sw46.1, sw47.1
row10: A1.21 (GPIO16), sw48.1, sw49.1, sw50.1, sw51.1, sw52.1
row11: A1.20 (GPIO15), sw53.1, sw54.1, sw55.1, sw56.1, sw57.1
row12: A1.19 (GPIO14), sw58.1, sw59.1, sw60.1, sw61.1, sw62.1
unique button a: sw6.1
unique button b: A1.4 (GPIO2), A1.5 (GPIO3), D6.1 (K)

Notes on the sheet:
total= 61 keys
this is the rotary encoder wiring (the knob)
switch wiring
this is the raspberry pico and ive wired it here using the global labels

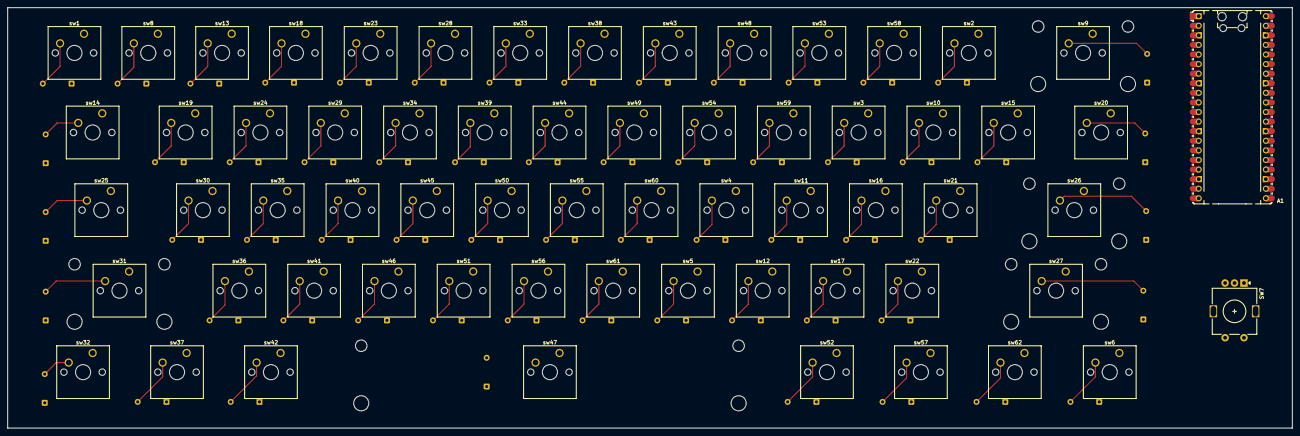
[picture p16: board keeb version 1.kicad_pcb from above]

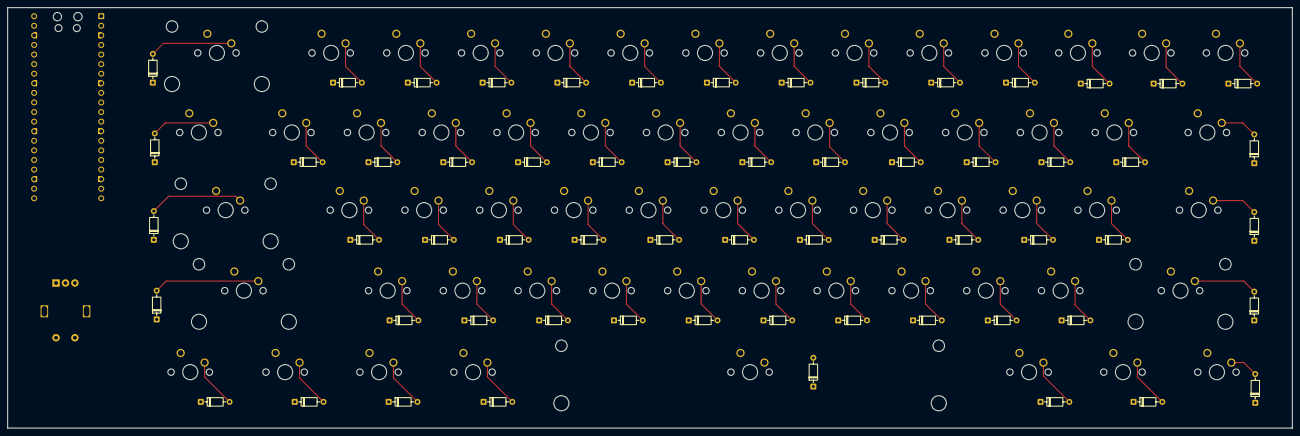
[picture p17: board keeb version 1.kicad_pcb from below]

Board: 2 copper layers, 340.4 x 111.4 mm, 124 parts (61 on the bottom side), 81 nets.

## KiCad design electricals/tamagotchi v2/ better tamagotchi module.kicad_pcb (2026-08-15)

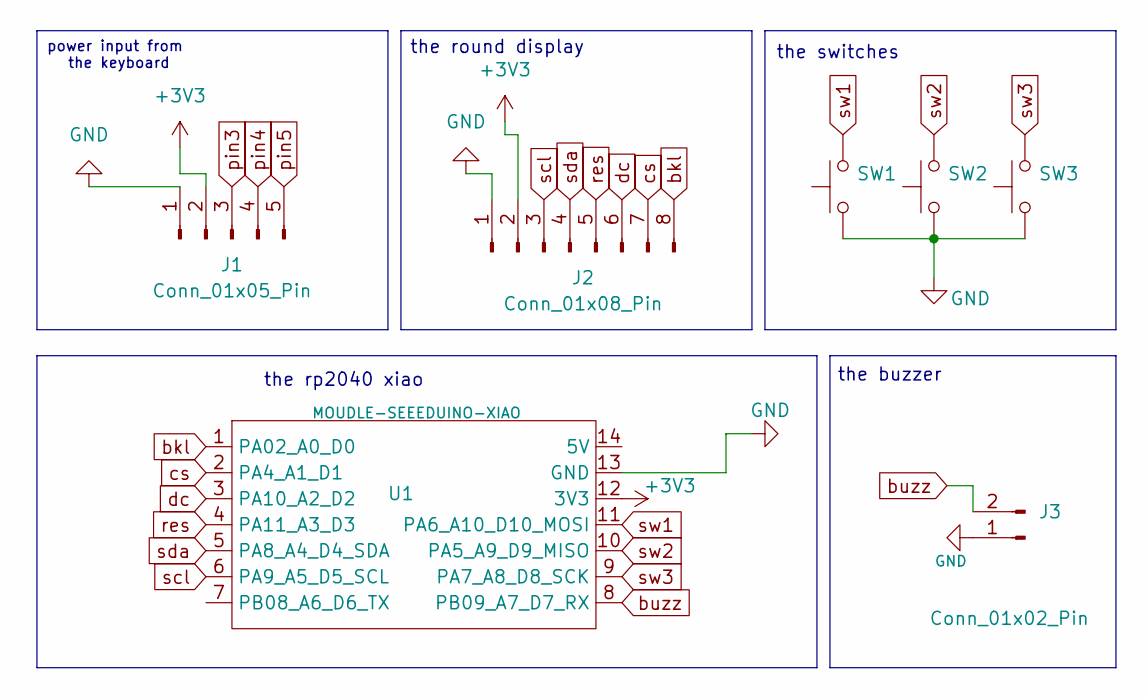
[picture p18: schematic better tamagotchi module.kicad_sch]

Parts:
J1: Conn_01x05_Pin; PinHeader_1x05_P2.00mm_Vertical
J2: Conn_01x08_Pin; PinHeader_1x08_P2.00mm_Vertical
J3: Conn_01x02_Pin; PinHeader_1x02_P1.00mm_Vertical
SW1, SW2, SW3: SW_Push; SW_PUSH_6mm
U1: MOUDLE-SEEEDUINO-XIAO; XIAO-Generic-Hybrid-14P-2.54-21X17.8MM

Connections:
+3V3: J1.2, J2.2, U1.12 (3V3)
GND: J1.1, J2.1, J3.1, SW1.1, SW2.1, SW3.1, U1.13 (GND)
bkl: J2.8, U1.1 (PA02_A0_D0)
buzz: J3.2, U1.8 (PB09_A7_D7_RX)
cs: J2.7, U1.2 (PA4_A1_D1)
dc: J2.6, U1.3 (PA10_A2_D2)
pin3: J1.3
pin4: J1.4
pin5: J1.5
res: J2.5, U1.4 (PA11_A3_D3)
scl: J2.3, U1.6 (PA9_A5_D5_SCL)
sda: J2.4, U1.5 (PA8_A4_D4_SDA)
sw1: SW1.2, U1.11 (PA6_A10_D10_MOSI)
sw2: SW2.2, U1.10 (PA5_A9_D9_MISO)
sw3: SW3.2, U1.9 (PA7_A8_D8_SCK)

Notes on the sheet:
power input from the keyboard
the buzzer
the round display
the rp2040 xiao
the switches

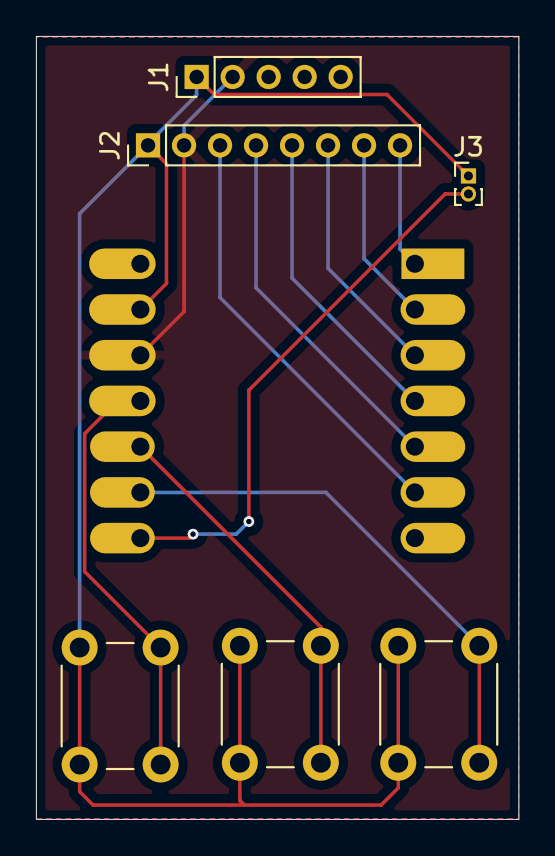
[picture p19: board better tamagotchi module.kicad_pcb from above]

Board: 2 copper layers, 26.8 x 43.5 mm, 7 parts (1 on the bottom side), 12 nets.

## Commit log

2026-08-13 Document bottom layer sketch in journal
    Added a description of the bottom layer sketch in the skeleton case manner.
2026-08-13 Rename keeb.step to keylouder pcb.step
    [keeb.step, keylouder pcb.step]
2026-08-13 Rename keylouder pcb.step to CAD/keylouder pcb .step
    [keylouder pcb .step]
2026-08-15 Add section for PCB creation in journal
    Added a new section to discuss PCB creation.
2026-08-15 Rename electricals/better tamagotchi module.kicad_pcb to electricals/tamagotchi/better tamagotchi module.kicad_pcb
    [better tamagotchi module.kicad_pcb]
2026-08-15 Rename electricals/better tamagotchi module.kicad_pro to electricals/tamagotchi/better tamagotchi module.kicad_pro
2026-08-15 Add better tamagotchi module schematic
    [better tamagotchi module.kicad_sch]
2026-08-15 Rename electricals/keeb version 1.kicad_pcb to electricals/keyboard/keeb version 1.kicad_pcb
    [keeb version 1.kicad_pcb]
2026-08-15 Rename electricals/keeb version 1.kicad_sch to electricals/keyboard/keeb version 1.kicad_sch
    [keeb version 1.kicad_sch]
2026-08-15 Rename electricals/tamagotchi module.kicad_pcb to electricals/tamagotchi/tamagotchi module.kicad_pcb
    [tamagotchi module.kicad_pcb]
2026-08-15 Rename electricals/tamagotchi module.kicad_sch to electricals/tamagotchi/tamagotchi module.kicad_sch
    [tamagotchi module.kicad_sch]
2026-08-15 Rename electricals/tamagotchi module.kicad_pro to electricals/tamagotchi/tamagotchi module.kicad_pro
2026-08-15 Rename electricals/rotary encoder module.kicad_sch to electricals/rotary encoder/rotary encoder module.kicad_sch
    [rotary encoder module.kicad_sch]
2026-08-15 Rename electricals/rotary encoder module.kicad_pro to electricals/rotary encoder/rotary encoder module.kicad_pro
2026-08-15 Rename electricals/rotary encoder module.kicad_pcb to electricals/rotary encoder/rotary encoder module.kicad_pcb
    [rotary encoder module.kicad_pcb]
2026-08-15 Rename electricals/led matrix.kicad_pcb to electricals/led matrix/led matrix.kicad_pcb
    [led matrix.kicad_pcb]
2026-08-15 Rename electricals/led matrix.kicad_pro to electricals/led matrix/led matrix.kicad_pro
2026-08-15 Rename electricals/led matrix.kicad_sch to electricals/led matrix/led matrix.kicad_sch
    [led matrix.kicad_sch]
2026-08-23 Rename electricals/better tamagotchi module.kicad_pcb to electricals/tamagotchi v2/ better tamagotchi module.kicad_pcb
    [better tamagotchi module.kicad_pcb]
2026-08-23 Rename electricals/better tamagotchi module.kicad_pro to electricals/tamagotchi v2 /better tamagotchi module.kicad_pro
2026-08-23 Rename better tamagotchi module.kicad_pro to better tamagotchi module.kicad_pro
2026-08-23 Update better tamagotchi module schematic file
    [better tamagotchi module.kicad_sch]
